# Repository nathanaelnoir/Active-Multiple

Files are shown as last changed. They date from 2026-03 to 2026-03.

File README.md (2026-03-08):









# Active Multiple

Active Multiple — a compact active buffered multiple for Eurorack modular synths.

## Contents

- Overview
- Features
- Quick start (KiCad 9)
- Files
- Build & assembly notes
- Testing
- High-level BOM
- License & contributing

## Overview

This repository holds the KiCad 9 project for an active multiple (buffered split). Designed by Dirty Dream — Nathanael Noir — the module accepts audio/CV inputs and provides low-impedance buffered outputs so signals can be split without loading downstream modules.

## Features

- Two independent channels (A & B).
- Per-channel quad buffering using TL074 op-amps (low-noise JFET-input quads).
- 3.5 mm TS jacks (QingPu / Thonkiconn footprint).
- Standard Eurorack power: +12 V / -12 V / GND via a 2x5 (10-pin) header.
- Mostly SMD (surface-mount) components; through-hole only for audio jacks and the Eurorack power header. Assembly is a mixed SMD + THT workflow.

## Quick start

1. Install KiCad 9 (this project was created/edited in KiCad 9).
2. Open the project: `kicad/buffer-module.kicad_pro`.
3. Inspect sheets and ERC, then run CV/PWR checks before exporting fabrication files.

## Files

- `kicad/buffer-module.kicad_sch` — top-level schematic (multi-sheet)
- `kicad/quad buffer.kicad_sch` — quad-buffer sheet (re-used per channel)
- `kicad/Europower +12 -12 GND.kicad_sch` — Eurorack power header sheet
- `kicad/buffer-module.kicad_pcb` — PCB
- `kicad/buffer-module.kicad_pro` — KiCad project file

Note: there is a single PCB layout file (`kicad/buffer-module.kicad_pcb`) for this project.

## Build & assembly notes

- Populate the PCB according to the schematic. Observe TL074 pin-1 orientation.
- Typical footprints:
	- Audio jacks: `AudioJacks2:Jack_3.5mm_QingPu_WQP-PJ398SM_Vertical` (vertical Thonkiconn-style)
	- Power connector: 2x5 Eurorack header (standard 10-pin)
- Add local decoupling (100 nF) on each op-amp power pin pair and bulk caps on rails.
- Double-check power-header orientation with your case header before applying power.

## Testing

1. With no inputs connected, power up and verify rails (+12 V / -12 V) at op-amp supply pins.
2. Feed a low-frequency sine into `Input A` and verify the outputs `OutA/OutB/OutC/OutD` reproduce it cleanly.
3. Connect multiple outputs to confirm splitting works without distortion or level loss.

## High-level BOM

- U1, U2 — TL074 (or compatible quad op-amp)
- J1..J9 — 3.5 mm TS jacks (vertical Thonkiconn/QingPu)
- Jpwr — 2x5 Eurorack power connector
- Resistors, caps, and decoupling components — see schematic for values and placement

For a detailed BOM, use KiCad's BOM export or ask me to generate a CSV from the project files.

### Bill of Materials (detailed)

| Designator(s) | Qty | Value / Part | Footprint | Datasheet |
|---|---:|---|---|---|
| C1, C2 | 2 | 10 µF | Capacitor_SMD:CP_Elec_5x5.4 | [datasheet](https://www.taydaelectronics.com/datasheets/files/a-1677.pdf) |
| C3–C8 | 6 | 100 nF | Capacitor_SMD:C_0805_2012Metric_Pad1.18x1.45mm_HandSolder | [datasheet](https://www.taydaelectronics.com/100nf-50v-smd-ceramic-chip-capacitor.html) |
| D1 | 1 | LED_Dual_A (bi-color) | LED_THT:LED_D3.0mm | [product](https://www.taydaelectronics.com/bi-color-led-3mm-red-green.html) |
| D2 | 1 | LED_Dual_B (bi-color) | LED_THT:LED_D3.0mm | [product](https://www.taydaelectronics.com/bi-color-led-3mm-red-green.html) |
| FB1, FB2 | 2 | Ferrite bead (small) | Inductor_SMD:L_0805_2012Metric_Pad1.05x1.20mm_HandSolder | [datasheet](https://www.taydaelectronics.com/datasheets/files/A-3191.PDF) |
| J1 | 1 | Jack_InA (3.5 mm TS) | AudioJacks2:Jack_3.5mm_QingPu_WQP-PJ398SM_Vertical | [datasheet](https://www.taydaelectronics.com/datasheets/files/w-qp-518ma_drawings.pdf) |
| J2 | 1 | Jack_InB (3.5 mm TS) | AudioJacks2:Jack_3.5mm_QingPu_WQP-PJ398SM_Vertical | [datasheet](https://www.taydaelectronics.com/datasheets/files/w-qp-518ma_drawings.pdf) |
| J3 | 1 | Jack_OutA-1 (3.5 mm TS) | AudioJacks2:Jack_3.5mm_QingPu_WQP-PJ398SM_Vertical | [datasheet](https://www.taydaelectronics.com/datasheets/files/w-qp-518ma_drawings.pdf) |
| J4 | 1 | Jack_OutA-2 (3.5 mm TS) | AudioJacks2:Jack_3.5mm_QingPu_WQP-PJ398SM_Vertical | [datasheet](https://www.taydaelectronics.com/datasheets/files/w-qp-518ma_drawings.pdf) |
| J5 | 1 | Jack_OutA-3 (3.5 mm TS) | AudioJacks2:Jack_3.5mm_QingPu_WQP-PJ398SM_Vertical | [datasheet](https://www.taydaelectronics.com/datasheets/files/w-qp-518ma_drawings.pdf) |
| J6 | 1 | Jack_OutB-1 (3.5 mm TS) | AudioJacks2:Jack_3.5mm_QingPu_WQP-PJ398SM_Vertical | [datasheet](https://www.taydaelectronics.com/datasheets/files/w-qp-518ma_drawings.pdf) |
| J7 | 1 | Jack_OutB-2 (3.5 mm TS) | AudioJacks2:Jack_3.5mm_QingPu_WQP-PJ398SM_Vertical | [datasheet](https://www.taydaelectronics.com/datasheets/files/w-qp-518ma_drawings.pdf) |
| J8 | 1 | Jack_OutB-3 (3.5 mm TS) | AudioJacks2:Jack_3.5mm_QingPu_WQP-PJ398SM_Vertical | [datasheet](https://www.taydaelectronics.com/datasheets/files/w-qp-518ma_drawings.pdf) |
| J9 | 1 | Conn_02x05_Odd_Even (Eurorack power header) | Connector_IDC:IDC-Header_2x05_P2.54mm_Vertical | [datasheet](https://www.taydaelectronics.com/datasheets/files/A-2939.pdf) |
| R1, R6 | 2 | 1 MΩ | Resistor_SMD:R_0805_2012Metric_Pad1.20x1.40mm_HandSolder | [SMD info](https://www.taydaelectronics.com/datasheets/files/SMD.pdf) |
| R2–R4, R7–R9 | 6 | 1 kΩ | Resistor_SMD:R_0805_2012Metric_Pad1.20x1.40mm_HandSolder | [SMD info](https://www.taydaelectronics.com/datasheets/files/SMD.pdf) |
| R5, R10 | 2 | 300 Ω | Resistor_SMD:R_0805_2012Metric_Pad1.20x1.40mm_HandSolder | [SMD info](https://www.taydaelectronics.com/datasheets/files/SMD.pdf) |
| TP1–TP3 | 3 | TestPoint | TestPoint:TestPoint_Pad_D1.5mm | ~ |
| U1, U2 | 2 | TL074 (quad op-amp) | Package_SO:SOIC-14_3.9x8.7mm_P1.27mm | [datasheet](https://www.taydaelectronics.com/datasheets/files/A-1137.PDF) |

## License & contributing

This repository is released under the MIT license. See `LICENSE` for full text.

Contributions, issues, and pull requests welcome. If you publish PCBs or panels based on this design, please credit the original author: Dirty Dream — Nathanael Noir.

---

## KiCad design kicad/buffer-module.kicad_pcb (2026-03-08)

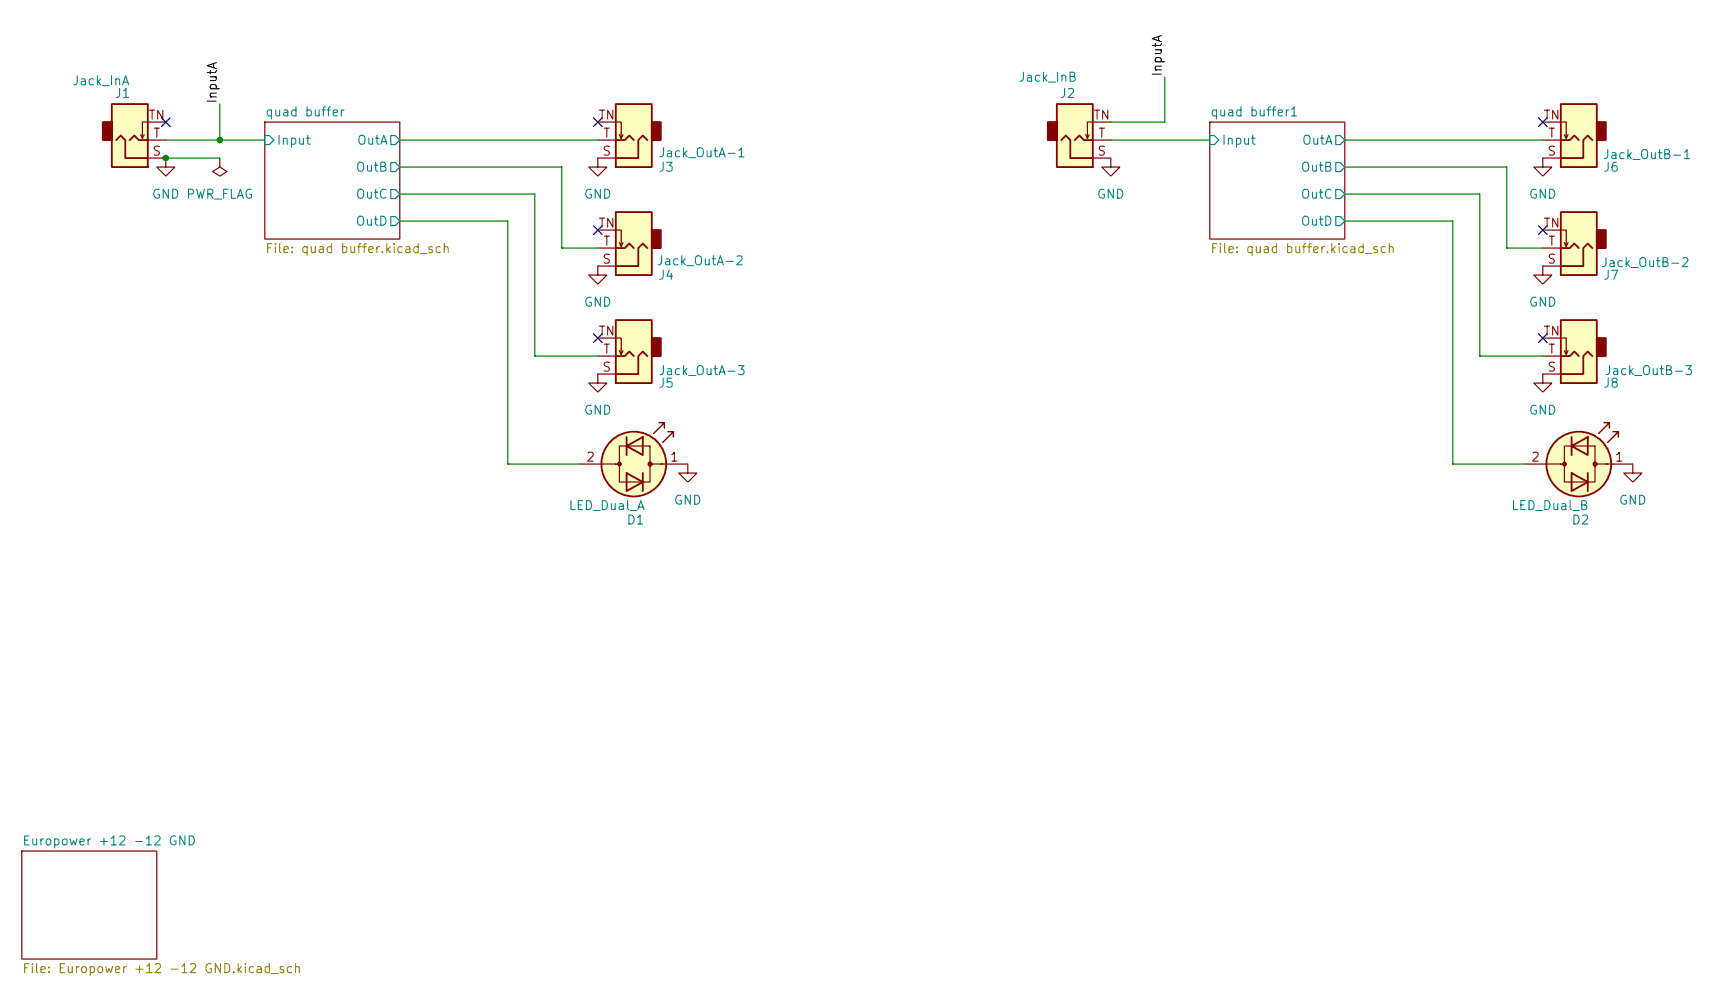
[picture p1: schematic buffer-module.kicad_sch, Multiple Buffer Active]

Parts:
D1: LED_Dual_A; LED_D3.0mm
D2: LED_Dual_B; LED_D3.0mm
J1: Jack_InA; Jack_3.5mm_QingPu_WQP-PJ398SM_Vertical
J2: Jack_InB; Jack_3.5mm_QingPu_WQP-PJ398SM_Vertical
J3: Jack_OutA-1; Jack_3.5mm_QingPu_WQP-PJ398SM_Vertical
J4: Jack_OutA-2; Jack_3.5mm_QingPu_WQP-PJ398SM_Vertical
J5: Jack_OutA-3; Jack_3.5mm_QingPu_WQP-PJ398SM_Vertical
J6: Jack_OutB-1; Jack_3.5mm_QingPu_WQP-PJ398SM_Vertical
J7: Jack_OutB-2; Jack_3.5mm_QingPu_WQP-PJ398SM_Vertical
J8: Jack_OutB-3; Jack_3.5mm_QingPu_WQP-PJ398SM_Vertical

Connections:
/InputA: J1.T, J2.TN; also elsewhere on the board
/quad buffer1/Input: J2.T; also elsewhere on the board
/quad buffer1/OutA: J6.T; also elsewhere on the board
/quad buffer1/OutB: J7.T; also elsewhere on the board
/quad buffer1/OutC: J8.T; also elsewhere on the board
/quad buffer1/OutD: D2.2 (AK); also elsewhere on the board
/quad buffer/OutA: J3.T; also elsewhere on the board
/quad buffer/OutB: J4.T; also elsewhere on the board
/quad buffer/OutC: J5.T; also elsewhere on the board
/quad buffer/OutD: D1.2 (AK); also elsewhere on the board
GND: D1.1 (KA), D2.1 (KA), J1.S, J2.S, J3.S, J4.S, J5.S, J6.S, J7.S, J8.S; also elsewhere on the board

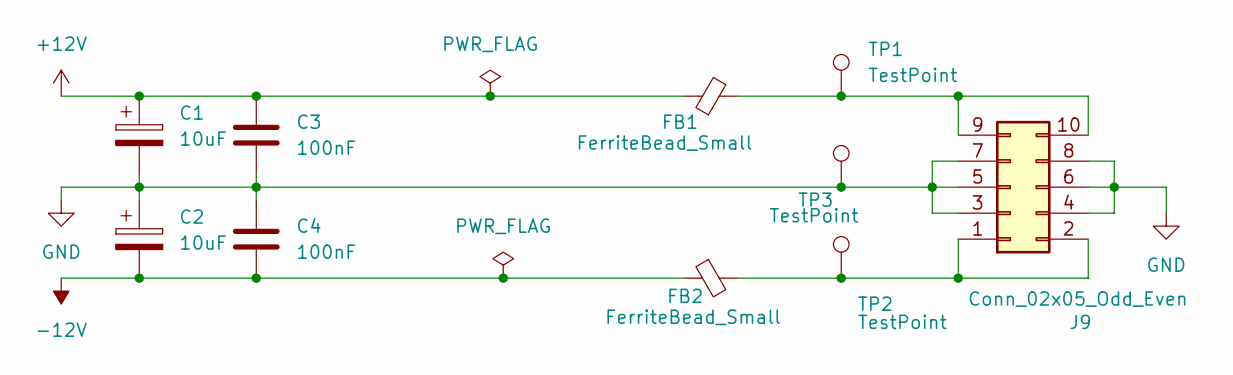
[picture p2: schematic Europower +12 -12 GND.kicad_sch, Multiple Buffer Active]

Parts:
C1, C2: 10uF; CP_Elec_5x5.4
C3, C4: 100nF; C_0805_2012Metric_Pad1.18x1.45mm_HandSolder
FB1, FB2: FerriteBead_Small; L_0805_2012Metric_Pad1.05x1.20mm_HandSolder
J9: Conn_02x05_Odd_Even; IDC-Header_2x05_P2.54mm_Vertical
TP1, TP2, TP3: TestPoint; TestPoint_Pad_D1.5mm

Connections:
+12V: C1.1, C3.1, FB1.1; also elsewhere on the board
-12V: C2.2, C4.2, FB2.1; also elsewhere on the board
GND: C1.2, C2.1, C3.2, C4.1, J9.3, J9.4, J9.5, J9.6, J9.7, J9.8, TP3.1; also elsewhere on the board
unnamed 13: FB2.2, J9.1, J9.2, TP2.1; also elsewhere on the board
unnamed 14: FB1.2, J9.9, J9.10, TP1.1; also elsewhere on the board

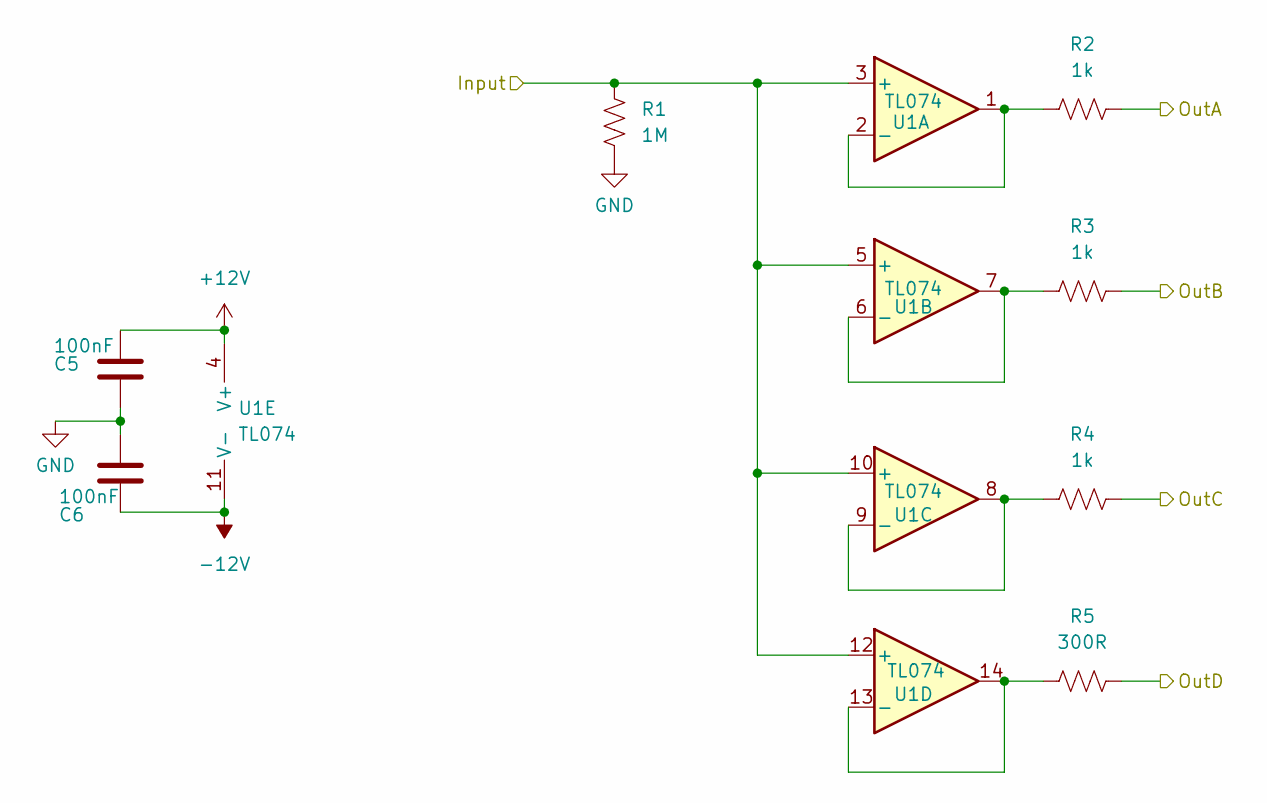
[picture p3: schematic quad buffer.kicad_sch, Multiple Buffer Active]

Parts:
C5, C6: 100nF; C_0805_2012Metric_Pad1.18x1.45mm_HandSolder
R1: 1M; R_0805_2012Metric_Pad1.20x1.40mm_HandSolder
R2, R3, R4: 1k; R_0805_2012Metric_Pad1.20x1.40mm_HandSolder
R5: 300R; R_0805_2012Metric_Pad1.20x1.40mm_HandSolder
U1: TL074; SOIC-14_3.9x8.7mm_P1.27mm

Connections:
+12V: C5.1, U1.4 (V+); also elsewhere on the board
-12V: C6.2, U1.11 (V-); also elsewhere on the board
/InputA: R1.2, U1.3 (+), U1.5 (+), U1.10 (+), U1.12 (+); also elsewhere on the board
/quad buffer/OutA: R2.2; also elsewhere on the board
/quad buffer/OutB: R3.2; also elsewhere on the board
/quad buffer/OutC: R4.2; also elsewhere on the board
/quad buffer/OutD: R5.1; also elsewhere on the board
GND: C5.2, C6.1, R1.1; also elsewhere on the board
unnamed: R2.1, U1.1, U1.2 (-)
unnamed: R3.1, U1.6 (-), U1.7
unnamed: R4.1, U1.8, U1.9 (-)
unnamed: R5.2, U1.13 (-), U1.14

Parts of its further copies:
C7, C8: 100nF; C_0805_2012Metric_Pad1.18x1.45mm_HandSolder
R6: 1M; R_0805_2012Metric_Pad1.20x1.40mm_HandSolder
R7, R8, R9: 1k; R_0805_2012Metric_Pad1.20x1.40mm_HandSolder
R10: 300R; R_0805_2012Metric_Pad1.20x1.40mm_HandSolder
U2: TL074; SOIC-14_3.9x8.7mm_P1.27mm

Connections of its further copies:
+12V: C7.1, U2.4 (V+); also elsewhere on the board
-12V: C8.2, U2.11 (V-); also elsewhere on the board
/quad buffer1/Input: R6.2, U2.3 (+), U2.5 (+), U2.10 (+), U2.12 (+); also elsewhere on the board
/quad buffer1/OutA: R7.2; also elsewhere on the board
/quad buffer1/OutB: R8.2; also elsewhere on the board
/quad buffer1/OutC: R9.2; also elsewhere on the board
/quad buffer1/OutD: R10.1; also elsewhere on the board
GND: C7.2, C8.1, R6.1; also elsewhere on the board
unnamed: R7.1, U2.1, U2.2 (-)
unnamed: R8.1, U2.6 (-), U2.7
unnamed: R9.1, U2.8, U2.9 (-)
unnamed: R10.2, U2.13 (-), U2.14

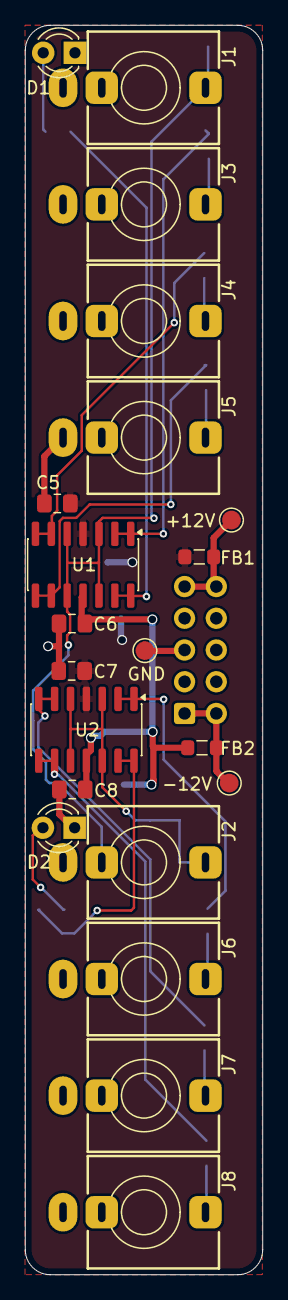
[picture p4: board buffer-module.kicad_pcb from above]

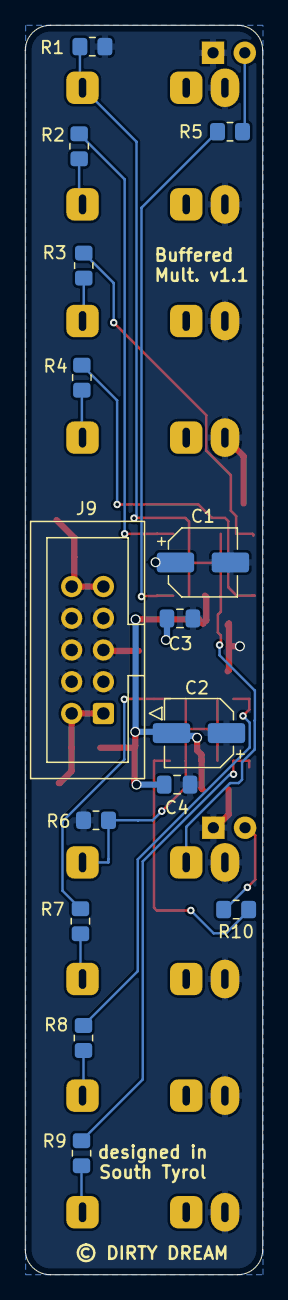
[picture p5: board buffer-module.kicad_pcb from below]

Board: 2 copper layers, 19.0 x 100.0 mm, 36 parts (15 on the bottom side), 23 nets.

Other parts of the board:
+12V: TestPoint; TestPoint_Pad_D1.5mm
-12V: TestPoint; TestPoint_Pad_D1.5mm
GND: TestPoint; TestPoint_Pad_D1.5mm

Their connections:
GND: GND.1; also elsewhere on the board
unnamed 13: -12V.1; also elsewhere on the board
unnamed 14: +12V.1; also elsewhere on the board

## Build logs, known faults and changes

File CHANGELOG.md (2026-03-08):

## Changelog

### v1.1
- Renamed test points to clearer names according to the power supply rails (`+12V`, `-12V`, `GND`).
- Improves readability and debugging during power verification.
- No electrical or PCB layout changes.

### v1.0
- Initial PCB release.
- Boards manufactured and assembled.
- Hardware tested successfully.

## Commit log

2026-02-11 Refactor code structure for improved readability and maintainability
    [Europower +12 -12 GND.kicad_sch, buffer-module.kicad_pcb, buffer-module.kicad_sch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]
2026-02-11 Update README with additional badges and clarify assembly component types
2026-02-11 Add initial KiCad project files for buffer module
    - Created buffer-module.kicad_prl with board settings, visibility options, and net inspector panel configurations.
    - Added lock file ~buffer-module.kicad_sch.lck to track user session information.
    [Europower +12 -12 GND.kicad_sch, buffer-module.kicad_sch, quad buffer.kicad_sch]
2026-02-11 Add footprint for Jack 3.5mm QingPu WQP-PJ398SM Vertical mount
2026-02-11 Refactor buffer-module: Remove unused silk layers and update footprint references
    - Removed multiple unused silk layer entries from buffer-module.kicad_pro to clean up the design.
    - Updated footprint references in buffer-module.kicad_sch from "AudioJacks2" to "Eurorack" for consistency across the schematic.
    - Deleted the lock file ~buffer-module.kicad_sch.lck as it is no longer needed.
    [buffer-module.kicad_pcb, buffer-module.kicad_sch]
2026-02-12 Refactor KiCad project files for improved layout and organization
    - Adjusted column widths in buffer-module.kicad_prl for better readability.
    - Cleared unnecessary DRC exclusions in buffer-module.kicad_pro to streamline design rules.
    - Updated sheet positions and properties in buffer-module.kicad_sch for enhanced clarity.
    - Realigned junctions and wires in quad buffer schematic for improved circuit flow and readability.
    - Corrected component positions and properties in quad buffer schematic to ensure accurate representation.
    [Europower +12 -12 GND.kicad_sch, buffer-module.kicad_pcb, buffer-module.kicad_sch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]
2026-02-12 Update README.md: Enhance badge section and add note on PCB layout file
2026-02-12 adding Gerber files
    [buffer-module.kicad_pcb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]
2026-02-12 zipping Gerber files
    [buffer-module-job.gbrjob]
2026-02-13 change of text
    [buffer-module.kicad_pcb]
2026-02-13 docs: add CONTRIBUTING.md with KiCad contribution workflow and PR checklist
2026-03-08 docs: add changelog and document v1.1 test point rename
    - Added Changelog section to README
    - Documented v1.1 schematic update (test point names aligned with power rails)
    - Noted that v1.0 boards were manufactured and tested successfully
    [Europower +12 -12 GND.kicad_sch, buffer-module.kicad_pcb, buffer-module.kicad_sch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]

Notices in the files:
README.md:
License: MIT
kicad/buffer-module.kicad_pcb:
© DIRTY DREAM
